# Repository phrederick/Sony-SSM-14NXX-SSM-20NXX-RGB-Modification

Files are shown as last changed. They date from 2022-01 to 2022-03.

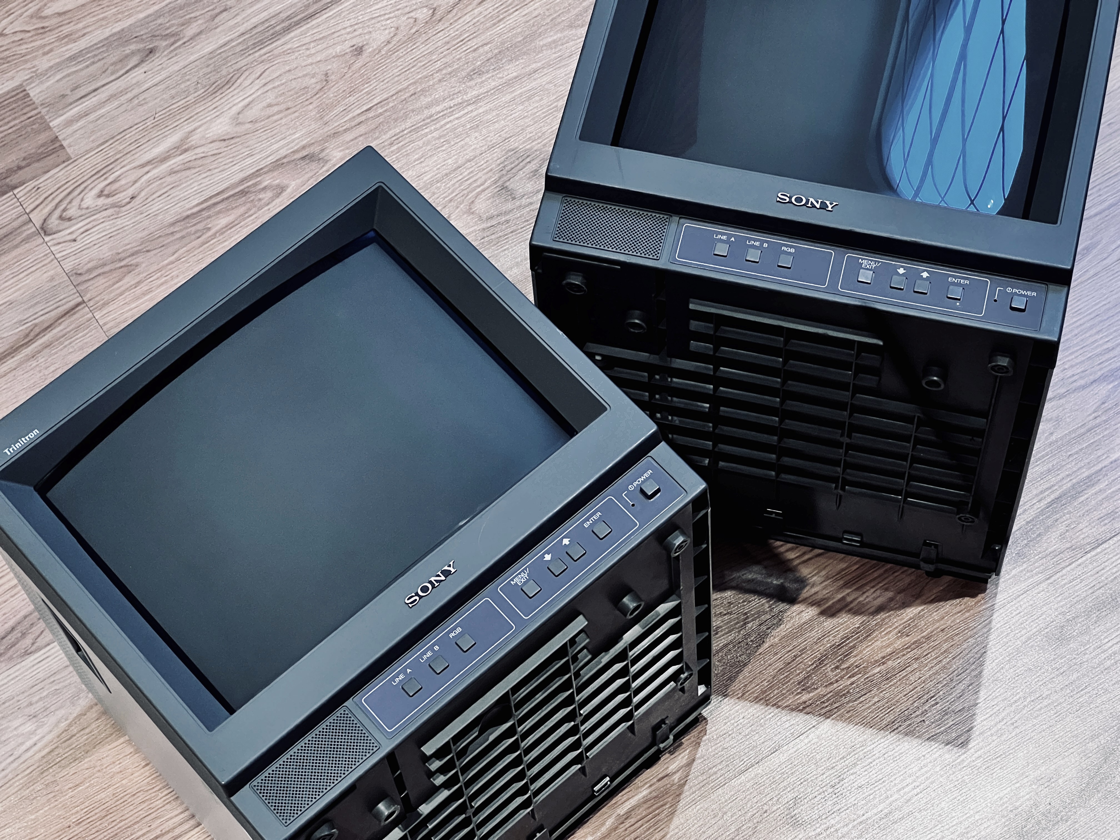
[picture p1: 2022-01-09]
Faceplate Decals/10 x 10mm Holes - Line A + Line B + RGB/10 x 10mm Holes - Line A + Line B + RGB - Example Image.jpg

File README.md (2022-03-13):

# SSM-14NXX / SSM-20NXX RGB Modification

- [Overview](#overview)
- [Who this guide is for](#who-this-guide-is-for)
    - [PVM models](#pvm-models)
- [Tools List](#tools-list)
    - [Required](#required)
    - [Highly Recommended](#highly-recommended)
- [Parts List](#parts-list)
- [Step 1 - Dismantling the monitor](#step-1---dismantling-the-monitor)
    - [Step 1.1 - Removing the case](#step-11---removing-the-case)
    - [Step 1.2 - Detaching the Q board and releasing the Q board from the connector mounting plate](#step-12---detaching-the-q-board-and-releasing-the-q-board-from-the-connector-mounting-plate)
    - [Step 1.3 - Removing the A board](#step-13---removing-the-a-board)
- [Step 2 - Q board and mounting panel modifications](#step-2---q-board-and-mounting-panel-modifications)
    - [Q board and mounting panel modification images](#q-board-and-mounting-panel-modification-images)
- [Step 3 - A board modifications](#step-3---a-board-modifications)
    - [A board modification images](#a-board-modification-images)
- [Step 4 - Case / enclosure modifications](#step-4---case--enclosure-modifications)
    - [Case / enclosure modification images](#case--enclosure-modification-images)
    - [3D-printed front panel buttons](#3d-printed-front-panel-buttons)
    - [Reproduction faceplate decals](#reproduction-faceplate-decals)
- [References and acknowledgements](#references-and-acknowledgements)

## Overview
The purpose of this document is to explain how to modify a Sony SSM monitor to be able to support RGB. As a disclaimer, I am not an electronics engineer by any means, and all of the information contained within is collated from various sources online. This documentation is mostly for my own reference, but I do hope others find it useful too. While I have done this modification myself, I was standing on the shoulders of others the whole way.

Please note that there are actually multiple ways to achieve this mod, and that the more correct way is almost definitely to populate *all* missing components, but this documentation serves to outline the specific route that I took to achieve it.

## Who this guide is for
This guide is specifically for you if you own any of the following monitors, and wish to modify them to accept RGB:
|14" Models|20" Models|
|---|---|
|SSM-14N5A|SSM-20N5A|
|SSM-14N5E|SSM-20N5E|
|SSM-14N5U|SSM-20N5U|

### PVM models
This guide may also be useful to you if you own any of the monitors from the table below, as they are also based on the same chassis as the aforementioned 'SSM-XXXXX' monitors.

|14" Models|20" Models|Notes|
|---|---|-----|
|PVM-14N5A|PVM-20N5A|Moddable - see notes below
|PVM-14N5E|PVM-20N5E|Moddable - see notes below
|PVM-14N5MDE|--|Moddable - see notes below
|PVM-14N5U|PVM-20N5U|Moddable - see notes below
|PVM-14N6A|PVM-20N6A|This monitor already has RGB
|PVM-14N6E|PVM-20N6E|This monitor already has RGB
|PVM-14N6U|PVM-20N6U|This monitor already has RGB

Modifying the PVM models is slightly different, and perhaps even easier depending on your perspective. The mod differences specific to PVM models that I am aware of are:

1. **Important** - Your PVM may or may not have a connector and wiring harness pre-installed at connector CN403 on the A board. If your monitor does not have this connector + harness, then you will need to route your own wires between the A and Q boards, but **be aware** that Sony made a mistake with the PCB labelling for this connector and it is reversed. On the PCB, the red pin is labelled as being closest to the front of the monitor, but the red pin is actually the one closest to the corner of the PCB; all other inputs are respectively reversed too. Therefore, from the corner of the PCB to the front, the pinouts are: R, GND, G, GND, B, GND, and Audio. See the images section below for a picture with the corrected pinout.

2. You may not need to make the same jumper cuts on the A board as noted in the instructions below, as they may already be absent.

3. The BA7604N and MC14052BCP ICs may already be present on your model, which means you will not need to add them.

4. If your monitor already has a connector and wiring harness between CN402 on the A board and CN1302 on the Q board (which it likely will if your monitor has Line B), then you can route your RGB sync pin to the emitter pin at Q1312 which is equivalent to jumping a wire to ESYNC at CN1302. See the images section below for a picture showing where to make the connection.

5. In the case of the PVM-14N5MDE, you may not need to add the 10 ohm resistor at R032, as it may already be present.

|Image|Notes|
|-----|-----|
|| As per point 1 above, this image illustrates the corrected pinout for CN403. If you are wiring CN403 yourself because your PVM does not have a connector and wiring harness, keep this in mind. If you want to install your own pin header (as opposed to just soldering wires directly into the PCB holes), the type of header you need is one with a 2.54mm pitch.
||As per point 4 above, if your PVM already has a connector between CN402 on the A board and CN1302 on the Q board, you can put a jumper wire between these two points instead of running a wire between A board and Q board which is necessary for models without aforementioned wiring harness between CN402 & CN1302.

## Tools List
### Required
* Screwdriver
* Soldering iron (I used a TS100)
* Desoldering braid / Desoldering tool
* Solder (I used 0.7mm)
* Insulated wire

### Highly Recommended
* Multimeter
* Flux
* Side cutters

## Parts List
|Component|Description|Qty|Links|
|---|---|---|-----|
|Ceramic capacitor|Surface mount, non-polarised - 0.1µF|3|[Digi-Key - 445-1418-1-ND](https://www.digikey.com.au/product-detail/en/tdk-corporation/C2012X7R2A104K125AA/445-1418-1-ND/569084)|
|Resistor|Through hole - 75 ohm 0.25W|6|[Digi-Key - S75CACT-ND](https://www.digikey.com.au/product-detail/en/stackpole-electronics-inc/RNMF14FTC75R0/S75CACT-ND/2617815)|
|Resistor|Through hole - 10 ohm 0.25W|2|[Digi-Key - CF14JT10R0CT-ND](https://www.digikey.com.au/product-detail/en/stackpole-electronics-inc/CF14JT10R0/CF14JT10R0CT-ND/1830306)|
|Switch|Side actuated, through hole, right angle|2|[Digi-Key - P12233SCT-ND](https://www.digikey.com.au/product-detail/en/panasonic-electronic-components/EVQ-PC105K/P12233SCT-ND/593537)|
|BNC Connectors|Female socket|4|[Digi-Key - 2057-RF1-106-D-00-50-HDW-ND](https://www.digikey.com.au/product-detail/en/adam-tech/RF1-106-D-00-50-HDW/2057-RF1-106-D-00-50-HDW-ND/9830449)<br>[Jaycar - PS0658 (Australia)](https://www.jaycar.com.au/bnc-panel-socket-single-hole-mount/p/PS0658)|
|MC14052BCP|Integrated circuit|1|[eBay](https://www.ebay.com/sch/i.html?_from=R40&_trksid=p2380057.m570.l1313&_nkw=MC14052BCP&_sacat=0)|
|BA7604N|Integrated circuit|1|[eBay](https://www.ebay.com/sch/i.html?_from=R40&_trksid=p2334524.m570.l1313&_nkw=BA7604N&_sacat=0)|

## Step 1 - Dismantling the monitor
A note on safety: It goes without saying that working on CRTs has an element of risk as high voltages are involved. You can get a nasty zap or worse if you are not careful. There are lots of guides on YouTube on CRT safety and how to discharge them. I encourage you to educate yourself further on CRT safety so you're prepared for doing this mod.

At the high level, dismantling the monitor for this modification involves the following steps:
1. Removing the case
2. Removing the Q board (i.e. the panel + PCB with the connectors on it), and releasing the Q board from the connector mounting plate
4. Removing the A board (i.e. the main board that sits at the bottom of the monitor)

### Step 1.1 - Removing the case
1. Remove the 4 screws (2 per side) on the sides of the monitor.
2. Remove the 4 screws on the rear of the monitor, all of which are located near the bottom. Two on the outer perimeter of the case, and two on the connector panel.
3. Using the carry handles, pull the outer case off to the rear.

### Step 1.2 - Detaching the Q board and releasing the Q board from the connector mounting plate
1. Looking at the rear of the monitor, note that there are markings that suggest that you need to push down on the plastic frame below the input board.
2. Gently press down in the designated areas while pulling the Q board outward to release it.
3. This procedure is best illustrated in Steve @ Retro Tech's video [here](https://www.youtube.com/watch?t=320&v=-ifKYeq9aC4).
4. Disconnect the ribbon cables and ground wires.
5. Using a soldering iron + desoldering braid, or a desoldering tool, desolder all of the points where the Q board attaches to the connector mounting plate. Note that this includes 4 ground tab sections on the perimeter of the board.

### Step 1.3 - Removing the A board
1. Take a note / photo of all the connector locations.
2. Discharge and remove the anode cap. An example of how to remove and discharge the anode cap for PVM's is illustrated and explained in Steve @ Retro Tech's video [here](https://www.youtube.com/watch?t=184&v=AZBh8YaPbQg). You may also wish to review [this video](https://www.youtube.com/watch?v=JeX5Y7Amk0o) if you prefer to use the discharge tool method.
3. Disconnect the remaining connectors.
4. Hold the A board firmly at the back and pull it outwards. There are no screws or tabs holding it down.

## Step 2 - Q board and mounting panel modifications
Now that the Q board has been released from the mounting plate, you can add the required components. I did it by first adding the BNC connectors to the mounting plate and soldering wire into the solder cup terminals which I then fed through the appropriate holes in the Q board. I then used insulated wires on the BNC ground lugs that wrapped around and attached to a single ground terminal on the Q board / mounting plate.

Action|Part|Location / Notes|
------|----|----------------|
Add component|75 ohm resistor|R1339|
Add component|75 ohm resistor|R1344|
Add component|75 ohm resistor|R1346|
Add component|75 ohm resistor|Tieing BNC pin directly to ANA-R at CN1303. You can attach to the emitter pin at Q1308|
Add component|75 ohm resistor|Tieing BNC pin directly to ANA-G at CN1303. You can attach to the emitter pin at Q1309|
Add component|75 ohm resistor|Tieing BNC pin directly to ANA-B at CN1303. You can attach to the emitter pin at Q1310|
Add component|Insulated wire|Tieing the Sync BNC pin to EXT SYNC at CN402 on A board|
Add component|Insulated wire|**Optional** - Tieing AUDIO at CN1303 to emitter pin at Q1305|

The optional jumper wire for the Audio means that the RGB and Line A will share the same 'Audio In' jack.

### Q board and mounting panel modification images
Image|Notes|
-----|-----|
||Q board, showing all component modification locations.|
||Q board, showing an example of how to attach the BNC connectors.|
||Q board and A board, showing an example of how to connect the sync wire.|

## Step 3 - A board modifications
Modifying the A board is pretty straight-forward. It's just a matter of removing and adding a few components. As noted earlier, some of these changes are not necessary if you are modifying the **non-SSM** variants based on the same chassis.

Action|Part|Location / Notes|
------|----|----------------|
Remove component|Jumper wire|JW401|
Remove component|Jumper wire|JW402|
Remove component|Jumper wire|JW403|
Add component|10 ohm resistor|R030|
Add component|10 ohm resistor|R032|
Add component|SMD capacitor|C310|
Add component|SMD capacitor|C311|
Add component|SMD capacitor|C312|
Add component|MC14052BCP|IC401|
Add component|BA7604N|IC402|
Add component|Tactile switch|S006|
Add component|Tactile switch|S008|

### A board modification images
Image|Notes|
-----|-----|
||A board, showing all component modification locations.|
||A board, detailed image showing where the ICs and jumper wire cuts / removals are to be made.|
||A board, detailed image showing where to attach the SMD capacitors.|
||A board, detailed image showing where to attach the 10 ohm resistors.|
||A board, detailed image showing where to attach the tactile switches.|

## Step 4 - Case / enclosure modifications
You will need to make some minor finishing touches to the case. Specifically:
1. Cutting holes in the rear panel plastic so the BNC connectors can poke through. One way you can do this is by using a scalpel to cut a rough but slightly smaller diameter circle out from behind and then roll up some 240 grit sandpaper and sand down the remaining overlap.
2. Cutting holes in the front panel plastic so you can reach the tactile buttons used for switching between your two inputs (Line A and RGB).
3. Adding labels for your new inputs and buttons.

### Case / enclosure modification images
Image|Notes|
-----|-----|
||Rear panel, showing an example of how to modify the rear panel.|

### 3D-printed front panel buttons
If you have access to a 3D printer, then you can print yourself some face buttons using the STL file here: https://www.thingiverse.com/thing:5029004. The STL file is also available on this GitHub page in the '..\Faceplate Button' directory. Kudos to 'galaxius' for kindly designing and printing the buttons for my own modified monitors.

Alternatively, for a small fee, I can provide you with two 3D printed buttons for switching between RGB and Line A. If you are interested, you can drop me an email: oo2@outlook.com. The cost is $5 AUD + shipping for 2 buttons. I can also sand and paint them for you for an additional $5 AUD - I will paint them with three coats of Tamiya Acrylic.

If you are using the suggested switches (or ones with very similar dimensions), the 3D printed buttons should remain captive in the hole and rest neatly against the switch acutator. Note that you will still need to punch or cut a square hole in the vinyl sticker so the button can protrude through.

Image|Notes|
-----|-----|
||An example of how these buttons can look once they are installed after the necessary modifications are done to the vinyl sticker.|
||Buttons unpainted / unsanded.|
||Buttons painted / face sanded.|
||Button video - view from inside case.|
||Button video - view from front (unsanded + painted prototype button)|

### Reproduction faceplate decals
With gracious thanks to Industrial Designer, Evan Twyford, we now have templates for creating reproduction faceplate decals to suit monitors with the following configurations:

* Modified monitors with 7mm x 7mm button holes for Line A, and RGB. Suitable for monitors using 3D-printed buttons available on this GitHub page - Note: **currently untested** - if you have created a panel with this configuration, please let me know your results!
* Modified monitors with 10mm x 10mm button holes for Line A, and RGB. Suitable for monitors where you have your own solution for faceplate buttons and / or desire the original 10mm x 10mm hole.
* Original N6 monitors with 10mm x 10mm button holes for Line A, Line B, and RGB. Suitable for monitors where Line B is also present, as is the case for original, unmodified N6 models.

The decals are available on this GitHub page in the '..\Faceplate Decals' directory. As advised by Evan, the PDF drawing will have just about all the info you need to know to have these decals recreated. Separate DXF file for the die-cut pattern is also provided if needed, but it is included in a layer in the PDF.

If you are based in the US, you may find the following information provided by Evan regarding printers / vendors useful:

* [Gamma Ray Graphics](https://www.gammaraygraphics.com/) - cheaper option (~$20 ea), colour matching not perfect, thinner labels.
* [MPC - Metalphoto of Cincinnati](https://www.mpofcinci.com/) - $400 setup cost, polyester nameplates are an accurate reproduction. This company, or similar, should have no problem meeting OEM spec.

Image|Notes|
-----|-----|
||An example image provided by Evan Twyford showing 2 PVM-14N6U monitors with reproduction faceplate decals produced by Gamma Ray Graphics|

## References and acknowledgements
* nrq for his additional notes on modding the PVM-14N5MDE; specifically regarding the R032 resistor, and the pin-header size.
* Sam Theodore Byrd for PVM model-specific note on where to connect the external sync pin.
* Evan Twyford, Industrial Designer - for creating and providing faceplate decal design files to suit original and modified monitors.
* galaxius for designing and printing 3D-printable face buttons.
* The official service manual for the 'SIIA' chassis: http://diagramas.diagramasde.com/otros/SSM-20N5U_9976686010-00e.pdf
* freakaftr8's 'Sony SSM-20N5U RGB mod!' guide on the Shmups forum: https://shmups.system11.org/viewtopic.php?f=6&t=66067&p=1400712#p1400712
* freakaftr8 for his patience with answering my questions on Reddit and providing additional guidance.
* santiis2010's 'PVM 14N5U to 14N6U' guide on Reddit: https://www.reddit.com/r/crtgaming/comments/i36ydq/re_doing_the_post_of_rgb_modding_for_pvm_14n5u_to/
* santiis2010 for his help with answering my questions on Facebook.
* Steve @ Retro Tech for his excellent videos on a broad range of CRT-related topics.
* Keith Gable for his 'Cap list and RGB mod part list' spreadsheet: https://onedrive.live.com/view.aspx?resid=780863C57629ADCC!1093221&ithint=file%2cxlsx&authkey=!APah2XIIKrw75wk
* The 'Professional & Broadcast CRT Monitors' and 'The CRT Collective' Facebook groups.
* The '/r/crtgaming' subreddit.

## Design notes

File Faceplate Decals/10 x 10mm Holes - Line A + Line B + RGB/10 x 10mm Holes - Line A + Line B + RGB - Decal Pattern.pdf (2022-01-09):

## Material Specication:

Adhesive backed vinyl or similar. Printed and diecut with added lm laminate to protect from scratching. 0.6 mm overall material thickness (substrate + lm laminate +adhesive). Decals may be thinner than 0.6mm, however, due to irregularities in the molded plastic case, the decal may not sit totally smooth when applied. Clean surface well before application to remove dirt and adhesive residue from old decal.

## Designer’s Notes:

Button hole spacing is annotated in drawing. Button holes are 10mm x 10mm with 1mm radius corners. Labels are created using Helvetica Neue LT Com Extended 53 typeface. Print artwork and dieline (toolpath cutline) are separated into individual layers in this PDF. Verify reference dimensions before cutting.

## Color Specs:

Trinitron Grey
Pantone 425 C
RGB 84 88 89
HEX/HTML 545859
CMYK 63 51 45 33

Cut Pattern

White
PANTONE 11-0601 TPG
Bright White
RGB 245 247 246
HEX/HTML F5F7F6

## Part Name: PVM-14N6U_Faceplate_Decal_OEM_Style

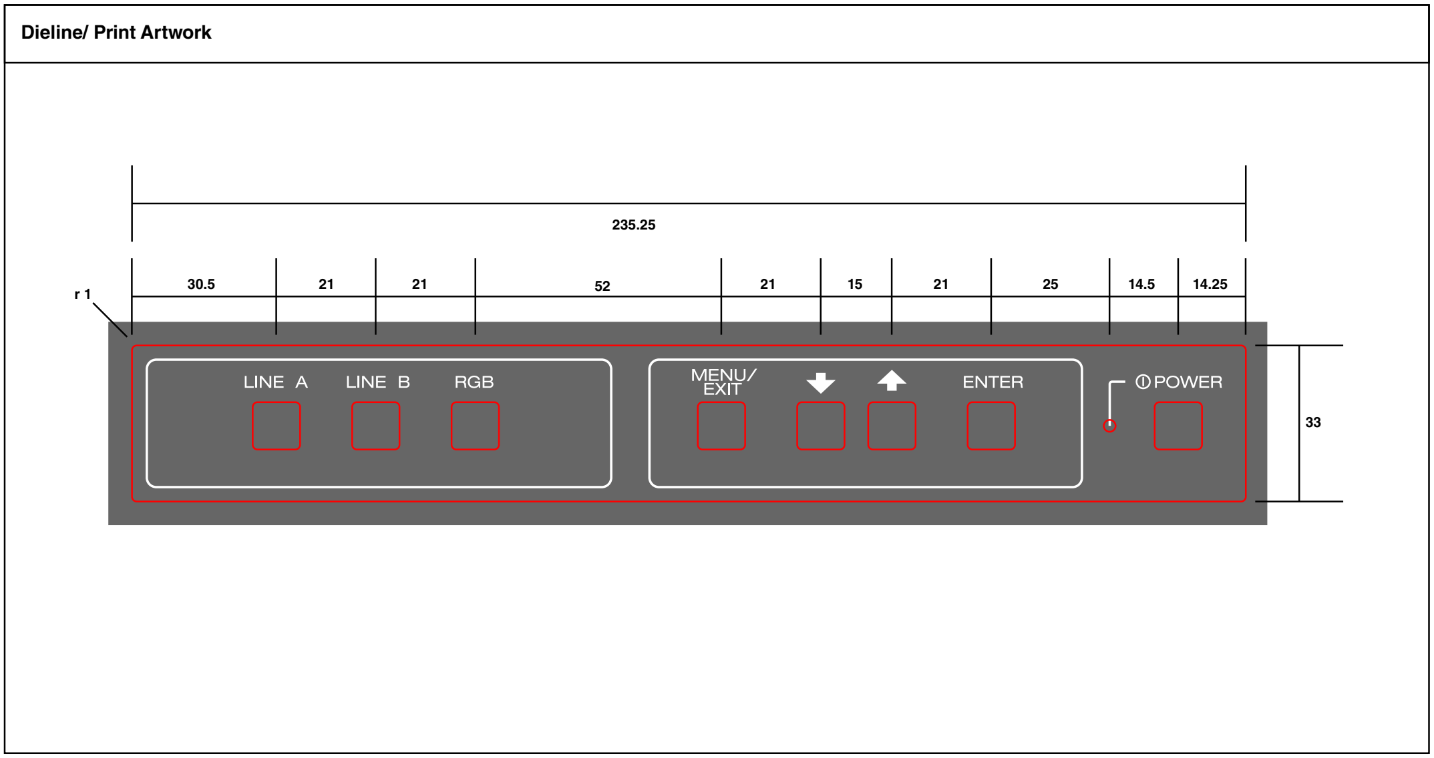
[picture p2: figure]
Dieline/ Print Artwork

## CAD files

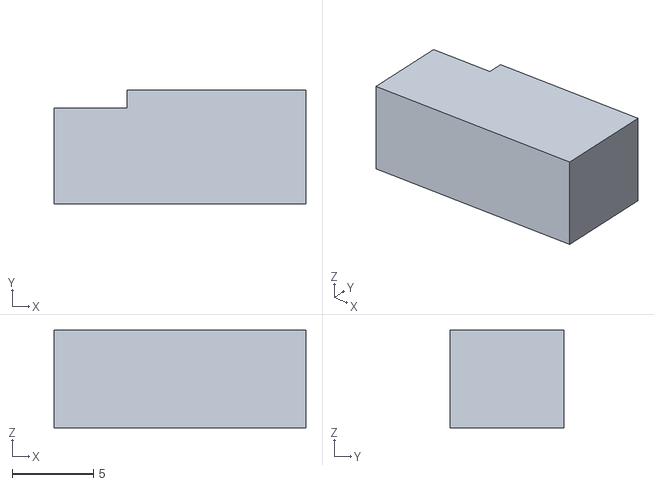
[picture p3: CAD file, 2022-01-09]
Faceplate Button/Sony_SSM_Monitor_Button.stl
15.5 x 7.00 x 6.00

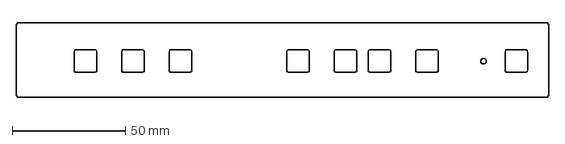
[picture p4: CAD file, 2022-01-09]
Faceplate Decals/10 x 10mm Holes - Line A + Line B + RGB/10 x 10mm Holes - Line A + Line B + RGB - Cut Pattern.dxf
235.2 x 33.0 mm

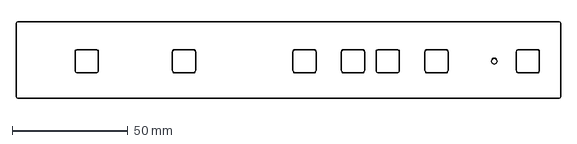
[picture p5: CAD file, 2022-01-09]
Faceplate Decals/10 x 10mm Holes - Line A + RGB/10 x 10mm Holes - Line A + RGB - Cut Pattern.dxf
235.2 x 33.0 mm

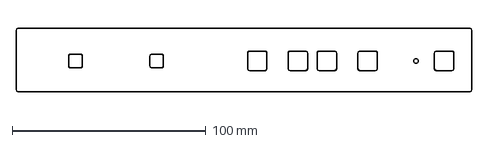
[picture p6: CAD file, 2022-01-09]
Faceplate Decals/7 x 7mm Holes - Line A + RGB/7 x 7mm Holes - Line A + RGB - Cut Pattern.dxf
235.2 x 33.0 mm

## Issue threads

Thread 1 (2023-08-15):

Notes for PVM 14N5U implementation

brendanseattle, 2023-08-15:
Hi I used this on my PVM 14N5U and it worked great! Thought I'd add some notes about what I found.

- Desoldering the plate from the Q board is not necessary. You can add the BNCs to the plate, and screw on the associated ground tab and nut by using tweezers from the side. I opted to route some resistor legs in the througholes to connect the video signals and ground tabs
- wires are not needed for BNC ground, you can just use the provided throughhole and a resistor leg to attach it
- R032 resistor is already present on this model, only R030 needs to be populated
- S008 is already present (along with S007), only S006 needs to be populated

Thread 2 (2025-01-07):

remove additional SMD shorts

znicolaou, 2025-01-07:
Hi @phrederick , very nice repo, I appreciate the guidance! I recently finished troubleshooting some issues I was having with the mod for my SSM-14N5U. Most importantly, I found some SMD shorts that needed to be removed (or replaced with appropriate capacitors) to get the RGB input to work.

Specifically, my Q board contained SMD shorts in place of the capacitors C1350-C1353 and my A board contained SMD shorts in place of capacitors C417-C420. These shorts connected the GND and RGB/Audio pins of CN1303 on the Q board and the corresponding pins of CN403 on the A board, and these changes are indeed indicated in the MARK LIST in the service manual [here](https://crtdatabase.com/crts/sony/sony-ssm-14n5u) on p. 72 and p. 78. Interestingly, the pictures of your board on the repo look different from mine, and the SMD shorts (marked with 000 indicating zero resistance on my board) appear to be replaced with SMD capacitors in your pictures, presumably as in the PVM models.

Also, my board silkscreen mixed up the labels for jumper wires JW401-JW403 relative to the service manual. I kept the (service manual) JW402 in place connecting pins 3 and 1 of IC401 rather than including the QA board jumper for the shared audio input port indicated in your guide.

In any case, the mod appears to be working well now...thank you for the detailed instructions!

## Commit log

2020-12-19 Added images and made a couple of other minor corrections.
2021-08-04 Added 3D-printed buttons
2021-08-04 GIFs of 3D printed buttons in action
2021-08-31 Added a picture of how the 3D-printed buttons look once installed
2021-10-04 Lowered price of 3D printed buttons
2021-10-24 Added link to STL file for 3D printing (thank you, galaxius!)
2022-01-09 Added repro faceplate decal design files - thank you, Evan Twyford!. Updated references / acknowledgements
    [10 x 10mm Holes - Line A + Line B + RGB - Cut Pattern.dxf, 10 x 10mm Holes - Line A + RGB - Cut Pattern.dxf, 7 x 7mm Holes - Line A + RGB - Cut Pattern.dxf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]
2022-01-27 Added note on external sync pin jumper wire for PVM models - thanks Sam Theodore Byrd!
